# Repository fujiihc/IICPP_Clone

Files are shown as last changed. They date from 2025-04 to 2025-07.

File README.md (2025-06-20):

# IICPP_Clone
Mark IIC+/++ Inspired Clone

## Overview
This goal of this project was to create a reasonably accurate "clone" of the Mesa Boogie Mark IIC+/++ Tube Amplifier. 
I was inspired by my love of Metallica and James Hetfield's rhythm playing, as well as my fascination with audio electronics.

These amplifiers can be considered legendary and are the subject of many discussions on what makes them so special and highly sought after.
Although a legitimate Mark IIC+ Reissue exists, as do many originals, these amps are often expensive, and vary in their component and feature choices.
I wouldn't consider this version to be a 100% perfect clone as there is not much accurate, detailed information on these amplifiers, and some of the schematics that are available have been noted to be incorrect. Certain components are also not readily available today, and so some design concessions have to be made. Modifications due to limited design information, component availability, limited budget, and design complexity were made. However, the core DNA and design choices of the original were followed as closely as possible and I  would consider this a reasonably faithful clone.
By having a more accessible, afforable, and reasonably accurate version, hopefully I can help contribute to others' tone chasing journeys, or help demystify (in some capacity) what makes these amps so special.

I currently do not own any Mesa Boogie amplifiers to base these designs off of. Instead, I have researched this amp in depth, scouring the internet for schematics, gut shots, and getting advice from others who have successfully built their own clones or similar amplifiers. 

A major goal of this project is to stay under a budget of $1800 (Half the price of a Reissue).

An important note, this project is for educational purposes and personal use only, and this repository is for documenting my learning progress and findings. I have no affiliation with Mesa Boogie or any sort of company or anything like that. I just like making stuff and playing guitar. Please don't sue me :)

## Table of Contents 
  **PROJECTS WERE CREATED IN KICAD 9.0**
  - [Custom Libraries](/Custom%20Libraries): Contains Custom Footprints for Parts Not Available from KICAD Default Libraries.
  - [Experiments](/Experiments): Contains Experimental Layouts and Ideas That Haven't Been Confirmed/Finalized.
  - [Graphic EQ](/Graphic%20EQ): Contains KICAD Projects with Schematics, PCB Designs, and Gerber Files for 5-Band EQ Driver and Slider Boards.
  - [Images](/Images): Contains Images for Various README's.
  - [Power Amp](/Power%20Amp): Contains KICAD Projects with Schematics, PCB Designs, and Gerber Files for Power Amp Boards.
  - [Power Supply](/Power%20Supply): Contains KICAD Projects with Schematics, PCB Designs, and Gerber Files for Power Supply Boards.
  - [Preamp](/Preamp): Contains KICAD Projects with Schematics, PCB Designs, and Gerber Files for Preamp Boards.

## Organizational/Research Spreadsheet
Contains Research Links, Bill of Materials, Instructions, Personal Findings, Notes, etc.
 - [Link to Google Sheet](https://docs.google.com/spreadsheets/d/1ZE0vuGfygjLFiTaHai0WybOM6v7LY0qXNIPXHzz1JHo/edit?usp=sharing)

## Google Drive
Contains Pictures, Schematics, Datasheets, Manuals, Etc. Just useful information I found along the way.
 - [Link to Google Drive](https://drive.google.com/drive/folders/1geqLoLI9ncoWVvD1H8Yl4hjtfwfBTIB6?usp=drive_link)

## Thank You's
The following people have been invaluable in the progress of this project, both directly and indirectly. Whether they posted schematics that they traced, or in-depth gut shots or photos of their own builds, or even answered my questions when I ran into roadblocks, I would like to thank them. I wouldn't have made this much progress without them:

  - [JAY OMEGA](https://boogieforum.com/members/jay-omega.83481/)

  - [JRB32](https://boogieforum.com/members/jrb32.41252/)

  - [DANO](https://boogieforum.com/members/dan__o.6723/)

  - [DANN VALENTINO](https://www.facebook.com/dann.valentino/)

  - [MATADOR](https://boogieforum.com/members/matador.84058/)

## To-Do/Future Plans

  - Create Modified C++ Compatible Preamp Board With Reverb
  - Create Modified C++ Compatible Preamp Board Without Reverb
  - Create Power Amp Board
  - Create Public Google Drive with Helpful Files (Pictures, Schematics, Datasheets, Manuals, Etc).

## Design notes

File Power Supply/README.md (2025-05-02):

# Power Supply

## Overview
The Power Supply for the IICPP contains the Main HT/B+ Taps as well as the Bias and Graphic EQ Power Supplies.

The board supports x2 (for 60W) and x4 (for 100W and Simul-Class) 300V 220uF Reservoir Caps.

## Status
  - Schematic, PCB Design, and Gerber for V1.0 of the Power Supply Board are Complete.
  - Gerbers generated for JLCPCB Manufacturing.

## Bill Of Materials
  - [Link to Google Sheet](https://docs.google.com/spreadsheets/d/1ZE0vuGfygjLFiTaHai0WybOM6v7LY0qXNIPXHzz1JHo/edit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)

## Notes
  - Bias Supply for SLOCLONE/DANO, Mesa Boogie, and JRB32 Schematics are incorrect. The correct Bias Supply Schematic is used in this V1.0, which was traced from original IIB and IIC+ Power Supply Boards.
  - Validated/Correct and Incorrect Bias Supply Versions and Validation Sources can be found in [Experiments](../Experiments)
    
## To-Do/Future Plans
  - Add/Remove Taps based on Power Transformer. Currently looking at Hammond 291ZZ.

## Images
Power Supply V1.0:
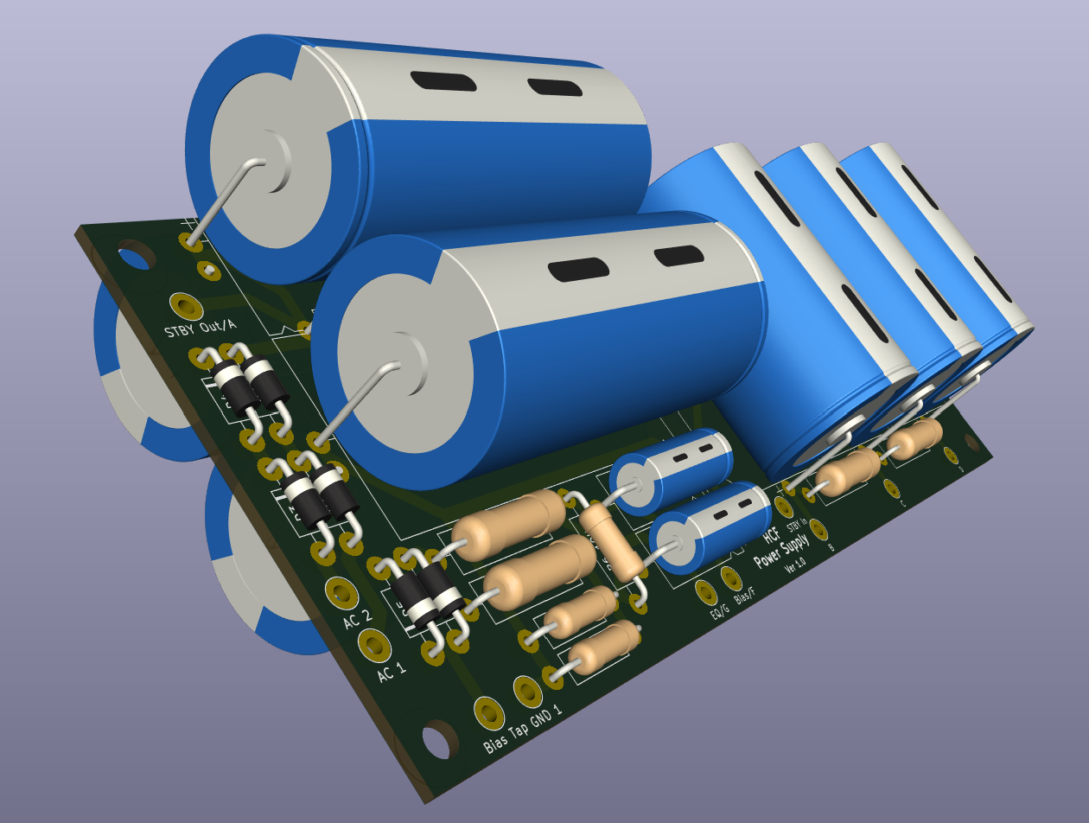
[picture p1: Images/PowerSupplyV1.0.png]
PowerSupplyV.10


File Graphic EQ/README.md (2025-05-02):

# Graphic EQ

## Overview
The 5-Band Graphic Equalizer for the IICPP consists of two parts, the EQ Driver and the EQ Slider Board. 

In conjunction, they can boost or cut frequencies at 80Hz, 240Hz, 750Hz, 2200Hz and 6600Hz.

The GEQ can be engaged in EQ Out, EQ In, and EQ Auto Modes, and can be footswitched.

EQ Out has the GEQ Off, EQ In has the GEQ In for Lead and Clean Modes, and EQ Auto engages the EQ when Lead is engaged.

## Status
  - Schematics, PCB Designs, and Gerbers for V1.0 of both the Driver and Slider Boards are Complete.
  - Gerbers generated for JLCPCB Manufacturing.

## Bill Of Materials
  - [Link to Google Sheet](https://docs.google.com/spreadsheets/d/1ZE0vuGfygjLFiTaHai0WybOM6v7LY0qXNIPXHzz1JHo/edit?gid=0#gid=0)

## Notes
  - MPSA70 is discontinued.
    - Options are NOS, finding drop-in replacement, or finding suitable alternatives for ALL transistors.
  - T322/T110 Tantalum Caps are expensive.
    - T322/T110 were used in some originals, but Cheaper Tant Caps (T356), Film Caps, or Orange Drop Caps also apparently work.
    
## To-Do/Future Plans
  - Order V1.0 Boards
  - Find Suitable Transistor Replacements

## Images
Slider V1.0:
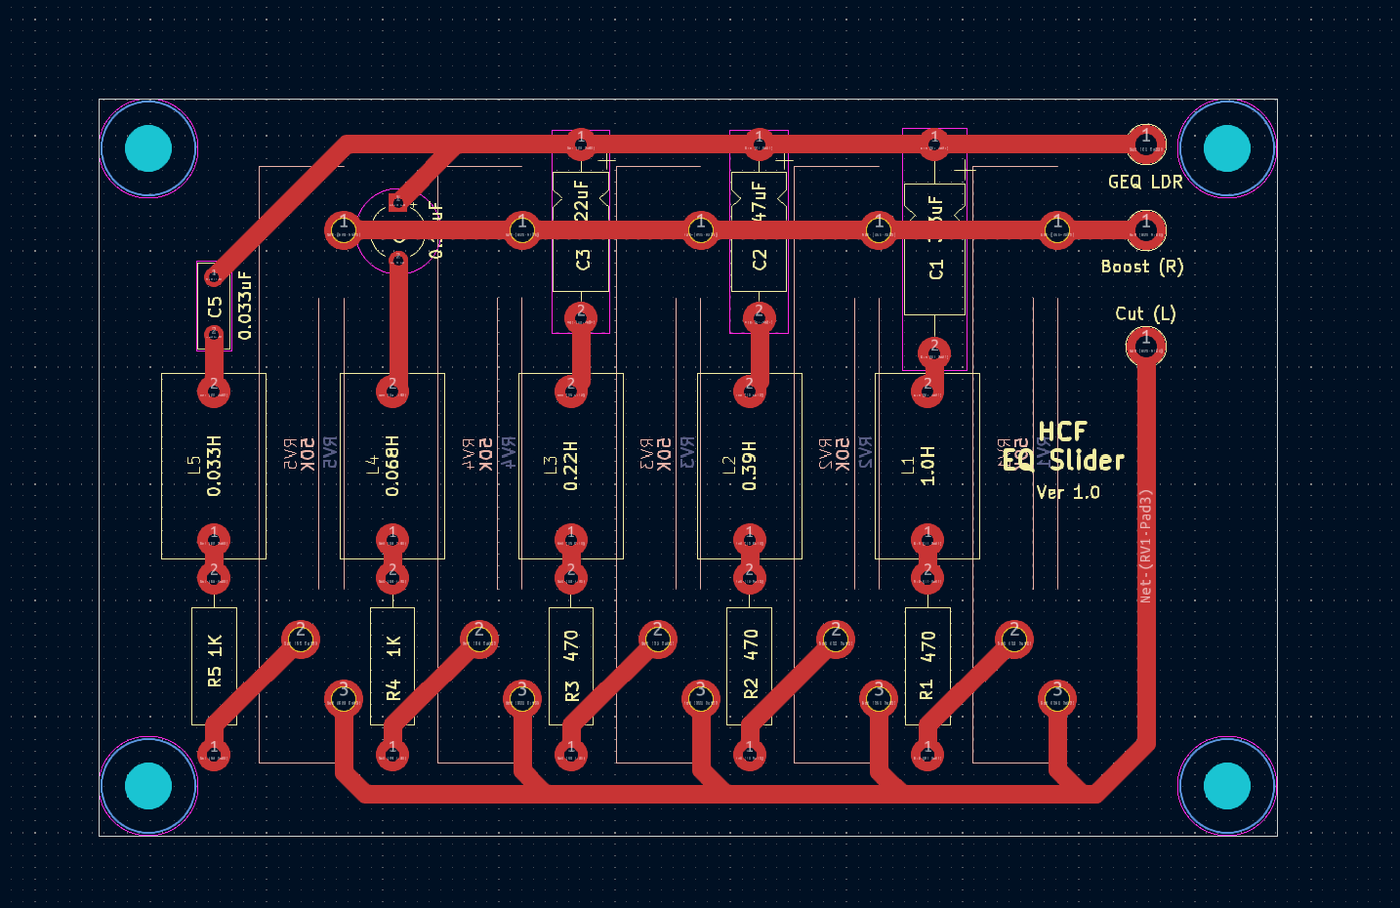
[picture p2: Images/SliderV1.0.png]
SliderV1.0


Driver V1.0:
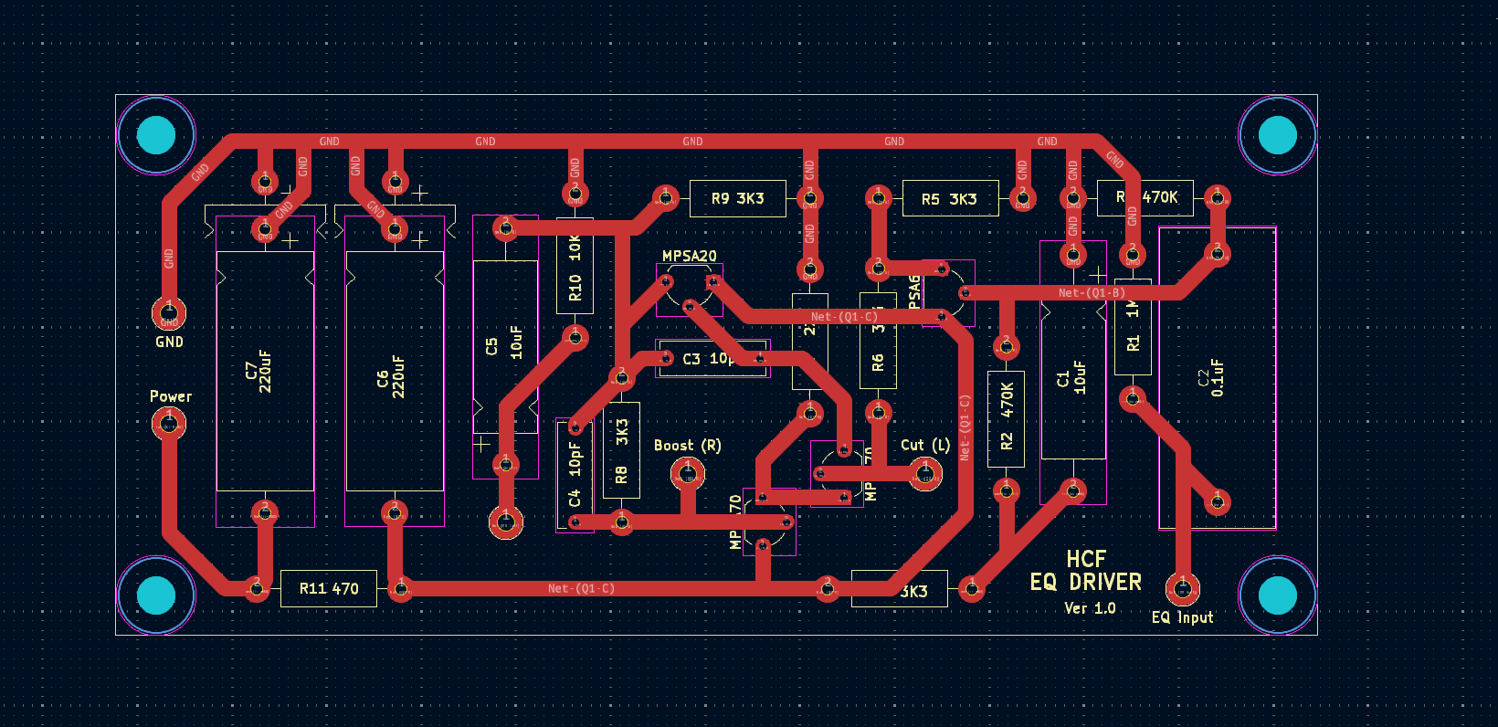
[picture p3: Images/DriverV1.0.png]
DriverV1.0


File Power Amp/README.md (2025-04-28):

# Power Amp

## Overview

## Status
  - 

## Bill Of Materials
  - [Link to Google Sheet](https://docs.google.com/spreadsheets/d/1ZE0vuGfygjLFiTaHai0WybOM6v7LY0qXNIPXHzz1JHo/edit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)

## Notes
  - 
## To-Do/Future Plans
  - 
## Images

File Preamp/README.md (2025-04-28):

# Preamp

## Overview
The Preamp for the IICPP has two switchable modes, Clean and Lead. There are also various Pull-Potentiometer/Switch Activated modes for tone shaping. 

It's important to note that the Tone Stack for the IICPP comes after the First Gain Stage, and before all the Following Gain Stages.
An optional mod for the IICPP is the "C++" Mod, which adds a little bit more gain on tap. This is an optional mod, but also switchable when implemented.

There are two versions of the Preamp here, one which has Reverb (R) and one with No Reverb (NR). the Reverb, when implemented, is footswitchable. The No Reverb version uses one less 12AX7 Preamp Tube, and uses fewer components as well.
The rest of the components and the schematic are the same.

## Status
  - 

## Bill Of Materials
  - [Link to Google Sheet](https://docs.google.com/spreadsheets/d/1ZE0vuGfygjLFiTaHai0WybOM6v7LY0qXNIPXHzz1JHo/edit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)

## Notes
  - 
## To-Do/Future Plans
  - 
## Images

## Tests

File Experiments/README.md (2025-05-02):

# Experiments

## Overview
Sometimes, schematics found online are different from what was actually implemented on the original IIC+'s.
The experiments folder is to mock up schematic and layout variations, for later validation. 

## Status
  - Correct Bias Supply Validated

## Sources
  - Bias Supply
    - Source 1: Original IIB Underside
    - Source 2: Original IIC+ Underside
    
## To-Do/Future Plans
  -

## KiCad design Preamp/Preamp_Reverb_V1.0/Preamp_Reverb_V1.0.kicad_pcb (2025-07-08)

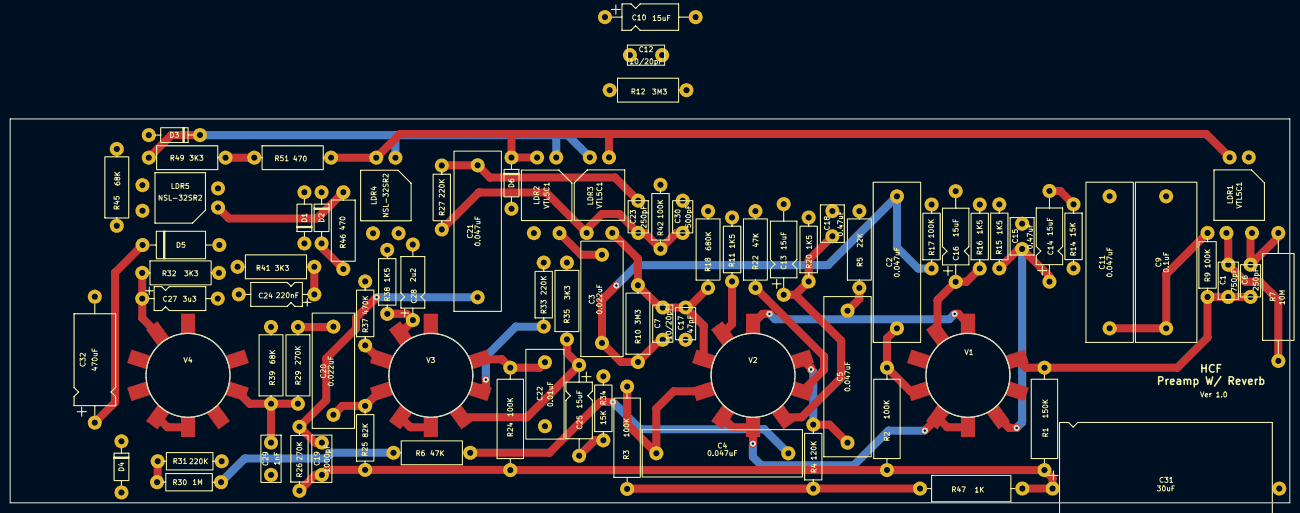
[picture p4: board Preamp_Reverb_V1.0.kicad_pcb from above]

Board: 2 copper layers, 254.0 x 76.2 mm, 84 parts (0 on the bottom side), 47 nets.

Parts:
C1: 750pF; 20_750pF_1KV_Cer_7.4_4.0_.6.4
C2, C4, C5, C11, C21: 0.047uF; 715P47354LAD3
C3, C20: 0.022uF; 715P22354KAD3
C6, C23: 250pF; 10_47_120_180_250_500pF_1KV_Cer_6.4_4.0_6.4
C7, C12: 10/20pF; 20_750pF_1KV_Cer_7.4_4.0_.6.4
C9: 0.1uF; 715P10454LAD3
C10, C13, C14, C16, C25: 15uF; CP_Axial_L11.0mm_D5.0mm_P18.00mm_Horizontal
C15, C18: 0.47uF; C_Rect_L7.2mm_W4.5mm_P5.00mm_FKS2_FKP2_MKS2_MKP2
C17: 47pF; 10_47_120_180_250_500pF_1KV_Cer_6.4_4.0_6.4
C19: 1000pF; 1000pF_1KV_Cer_9.4_4.0_6.4
C22: 0.01uF; 715P10354JAD3
C24: 220nF; CP_Axial_L10.0mm_D4.5mm_P15.00mm_Horizontal
C27: 3u3; CP_Axial_L10.0mm_D4.5mm_P15.00mm_Horizontal
C28: 2u2; CP_Axial_L10.0mm_D4.5mm_P15.00mm_Horizontal
C29: 1nF; 1000pF_1KV_Cer_9.4_4.0_6.4
C30: 500pF; 10_47_120_180_250_500pF_1KV_Cer_6.4_4.0_6.4
C31: 30uF; CP_Axial_L42.0mm_D26.0mm_P45.00mm_Horizontal
C32: 470uF; CP_Axial_L18.0mm_D8.0mm_P25.00mm_Horizontal
D1, D6: 6V 1W; D_DO-41_SOD81_P10.16mm_Horizontal
D2, D3, D4: 1N4006; D_DO-41_SOD81_P10.16mm_Horizontal
D5: 1N5352BRL; D_DO-201_P15.24mm_Horizontal
LDR1, LDR2, LDR3: VTL5C1; PerkinElmer_VTL5C
LDR4, LDR5: NSL-32SR2; PerkinElmer_VTL5C
R1: 150K; R_Axial_DIN0516_L15.5mm_D5.0mm_P20.32mm_Horizontal
R2, R3, R24: 100K; R_Axial_DIN0516_L15.5mm_D5.0mm_P20.32mm_Horizontal
R4: 120K; R_Axial_DIN0309_L9.0mm_D3.2mm_P12.70mm_Horizontal
R5: 22K; R_Axial_DIN0414_L11.9mm_D4.5mm_P15.24mm_Horizontal
R6, R22: 47K; R_Axial_DIN0414_L11.9mm_D4.5mm_P15.24mm_Horizontal
R7: 10M; R_Axial_DIN0617_L17.0mm_D6.0mm_P25.40mm_Horizontal
R9, R17, R42: 100K; R_Axial_DIN0309_L9.0mm_D3.2mm_P12.70mm_Horizontal
R10, R12: 3M3; R_Axial_DIN0414_L11.9mm_D4.5mm_P15.24mm_Horizontal
R11, R15, R16, R20, R38: 1K5; R_Axial_DIN0309_L9.0mm_D3.2mm_P12.70mm_Horizontal
R14, R34: 15K; R_Axial_DIN0309_L9.0mm_D3.2mm_P12.70mm_Horizontal
R18: 680K; R_Axial_DIN0414_L11.9mm_D4.5mm_P15.24mm_Horizontal
R25: 82K; R_Axial_DIN0309_L9.0mm_D3.2mm_P12.70mm_Horizontal
R26: 270K; R_Axial_DIN0309_L9.0mm_D3.2mm_P12.70mm_Horizontal
R27, R31, R33: 220K; R_Axial_DIN0309_L9.0mm_D3.2mm_P12.70mm_Horizontal
R29: 270K; R_Axial_DIN0414_L11.9mm_D4.5mm_P15.24mm_Horizontal
R30: 1M; R_Axial_DIN0309_L9.0mm_D3.2mm_P12.70mm_Horizontal
R32, R35, R41, R49: 3K3; R_Axial_DIN0414_L11.9mm_D4.5mm_P15.24mm_Horizontal
R37: 470K; R_Axial_DIN0309_L9.0mm_D3.2mm_P12.70mm_Horizontal
R39, R45: 68K; R_Axial_DIN0414_L11.9mm_D4.5mm_P15.24mm_Horizontal
R46, R51: 470; R_Axial_DIN0414_L11.9mm_D4.5mm_P15.24mm_Horizontal
R47: 1K; R_Axial_DIN0516_L15.5mm_D5.0mm_P20.32mm_Horizontal
V1, V2, V3, V4: 12AX7; VT9-ST-C

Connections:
D: R3.1, R4.1, R47.1
E: C19.1, C31.1, R1.1, R2.1, R24.1, R25.1, R26.1, R47.2
GEQ: LDR5.3, R45.1
GND: C15.2, C16.2, C17.2, C18.2, C27.2, C28.2, C29.2, C30.2, C31.2, C32.2, D1.2 (A), D5.2 (A), D6.2 (A), LDR4.3, LDR5.4, R11.2, R14.2, R15.2, R16.2, R17.2, R18.2, R20.2, R22.2, R31.2, R32.2, R33.2, R34.2, R35.2, R37.2, R38.2, R39.2, R41.2, R42.2, R45.2
LDR1+: D6.1 (K), LDR1.2 (+), LDR2.2 (+), LDR3.2 (+), LDR4.2 (+), R51.2
LDR2-: D3.1 (K), LDR2.1 (-), LDR3.1 (-), LDR4.1 (-), R49.2
Lead In: C3.2, LDR2.3
Lead Out: C7.2, C17.1, LDR3.4, R10.2, R18.1, V2.7 (G)
unnamed: C1.2, LDR1.4, R7.1
unnamed: C2.2, C3.1, C7.1, R10.1, R12.1, R17.1
unnamed: C4.2, R6.1
unnamed: C5.2, R5.1
unnamed: C6.2, LDR1.3, R7.2
unnamed: C9.1, C11.1, R9.2
unnamed: C12.1, R12.2
unnamed: C20.2, R29.1
unnamed: C21.2, C23.1, R27.1
unnamed: C23.2, C30.1, LDR3.3, R27.2, R42.1
unnamed: C25.2, R34.1
unnamed: D1.1 (K), LDR5.2 (+)
unnamed: D2.2 (A), R46.2
unnamed: C32.1, D5.1 (K), R49.1, R51.1
unnamed: LDR5.1 (-), R46.1
unnamed: C14.2, R14.1
unnamed: C2.1, R2.2, V1.6 (A)
unnamed: C16.1, R16.1, V1.8 (K)
unnamed: C1.1, C6.1, R1.2, R9.1, V1.1 (A)
unnamed: C14.1, C15.1, R15.1, V1.3 (K)
unnamed: V1.4 (F1), V1.5 (F1), V2.4 (F1), V2.5 (F1), V3.4 (F1), V3.5 (F1), V4.4 (F1), V4.5 (F1)
unnamed: V1.9 (F2), V2.9 (F2), V3.9 (F2), V4.9 (F2)
unnamed: C4.1, R3.2, V2.6 (A)
unnamed: C10.1, R11.1, V2.8 (K)
unnamed: C5.1, R4.2, V2.1 (A)
unnamed: R22.1, V2.2 (G)
unnamed: C13.1, C18.1, R20.1, V2.3 (K)
unnamed: C20.1, R25.2, V3.6 (A)
unnamed: R37.1, V3.7 (G)
unnamed: C28.1, R38.1, V3.8 (K)
unnamed: C22.1, R24.2, V3.1 (A)
unnamed: C25.1, R35.1, V3.3 (K)
unnamed: R30.2, R31.1, V4.7 (G)
unnamed: C27.1, R32.1, V4.8 (K)
unnamed: C19.2, C21.1, R26.2, V4.1 (A)
unnamed: C29.1, R29.2, R39.1, V4.2 (G)
unnamed: C24.1, R41.1, V4.3 (K)
Reverb In: R6.2, R30.1
Tank Out: R33.1, V3.2 (G)

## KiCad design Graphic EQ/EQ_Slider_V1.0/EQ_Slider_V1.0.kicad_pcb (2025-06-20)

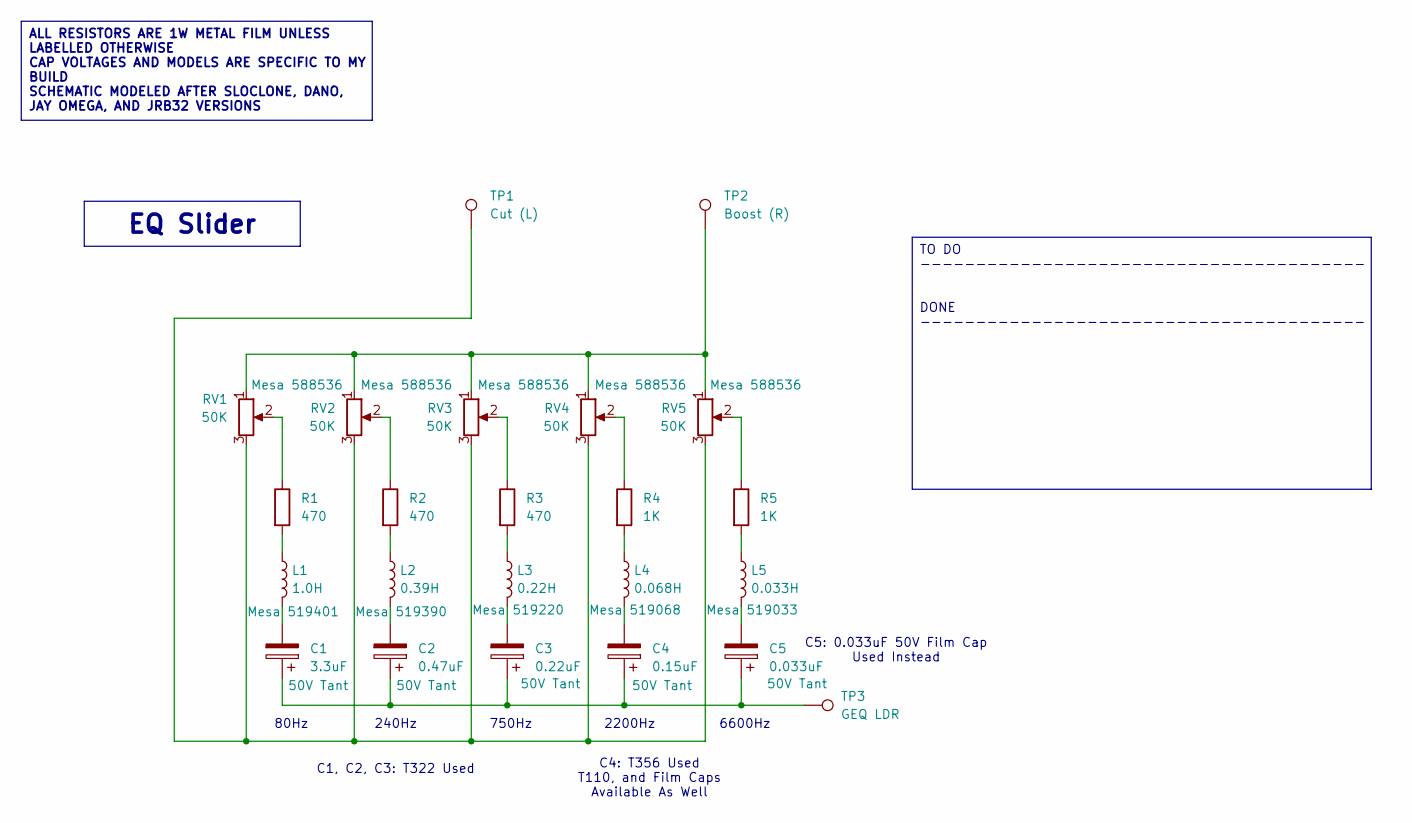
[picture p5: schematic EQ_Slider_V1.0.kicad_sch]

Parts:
C1: 3.3uF; CP_Axial_L11.0mm_D5.0mm_P18.00mm_Horizontal
C2: 0.47uF; CP_Axial_L10.0mm_D4.5mm_P15.00mm_Horizontal
C3: 0.22uF; CP_Axial_L10.0mm_D4.5mm_P15.00mm_Horizontal
C4: 0.15uF; CP_Radial_Tantal_D4.5mm_P5.00mm
C5: 0.033uF; C_Rect_L7.2mm_W2.5mm_P5.00mm_FKS2_FKP2_MKS2_MKP2
L1: 1.0H; MB Inductor
L2: 0.39H; MB Inductor
L3: 0.22H; MB Inductor
L4: 0.068H; MB Inductor
L5: 0.033H; MB Inductor
R1, R2, R3: 470; R_Axial_DIN0414_L11.9mm_D4.5mm_P15.24mm_Horizontal
R4, R5: 1K; R_Axial_DIN0414_L11.9mm_D4.5mm_P15.24mm_Horizontal
RV1, RV2, RV3, RV4, RV5: 50K; Mesa 588536
TP1: Cut (L); Out_Hole_3.4_1.8
TP2: Boost (R); Out_Hole_3.4_1.8
TP3: GEQ LDR; Out_Hole_3.4_1.8

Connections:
unnamed: C1.1, C2.1, C3.1, C4.1, C5.1, TP3.1
unnamed: C1.2, L1.2
unnamed: C2.2, L2.2
unnamed: C3.2, L3.2
unnamed: C4.2, L4.2
unnamed: C5.2, L5.2
unnamed: L1.1, R1.2
unnamed: L2.1, R2.2
unnamed: L3.1, R3.2
unnamed: L4.1, R4.2
unnamed: L5.1, R5.2
unnamed: R1.1, RV1.2
unnamed: R2.1, RV2.2
unnamed: R3.1, RV3.2
unnamed: R4.1, RV4.2
unnamed: R5.1, RV5.2
unnamed: RV1.1, RV2.1, RV3.1, RV4.1, RV5.1, TP2.1
unnamed: RV1.3, RV2.3, RV3.3, RV4.3, RV5.3, TP1.1

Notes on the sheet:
C5: 0.033uF 50V Film Cap Used Instead
750Hz
80Hz
240Hz
6600Hz
C4: T356 Used T110, and Film Caps Available As Well
2200Hz
C1, C2, C3: T322 Used
ALL RESISTORS ARE 1W METAL FILM UNLESS LABELLED OTHERWISE CAP VOLTAGES AND MODELS ARE SPECIFIC TO MY BUILD SCHEMATIC MODELED AFTER SLOCLONE, DANO, JAY OMEGA, AND JRB32 VERSIONS
TO DO ---------------------------------------- DONE ----------------------------------------
EQ Slider

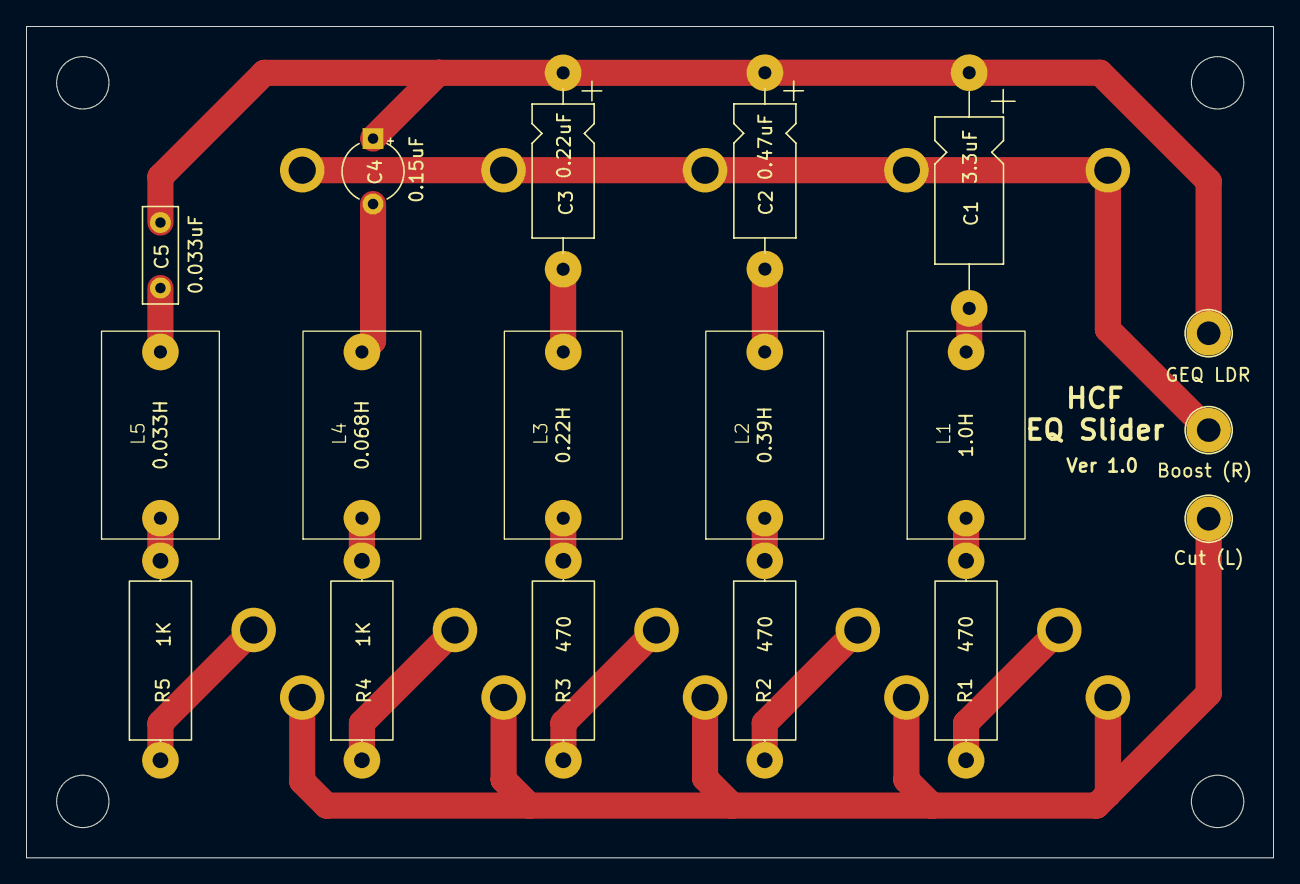
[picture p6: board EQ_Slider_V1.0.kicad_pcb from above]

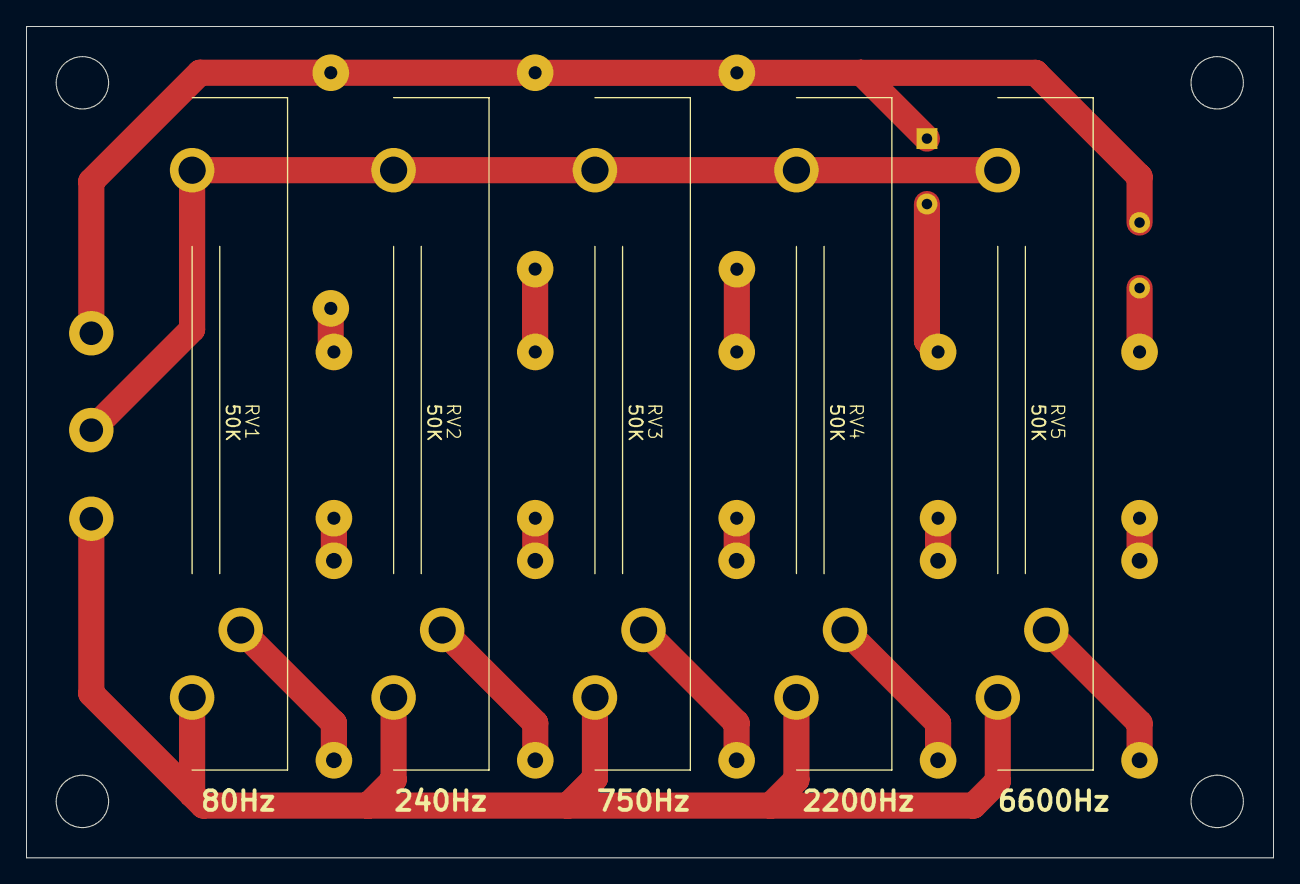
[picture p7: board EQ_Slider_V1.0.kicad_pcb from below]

Board: 2 copper layers, 95.3 x 63.5 mm, 23 parts (5 on the bottom side), 18 nets.

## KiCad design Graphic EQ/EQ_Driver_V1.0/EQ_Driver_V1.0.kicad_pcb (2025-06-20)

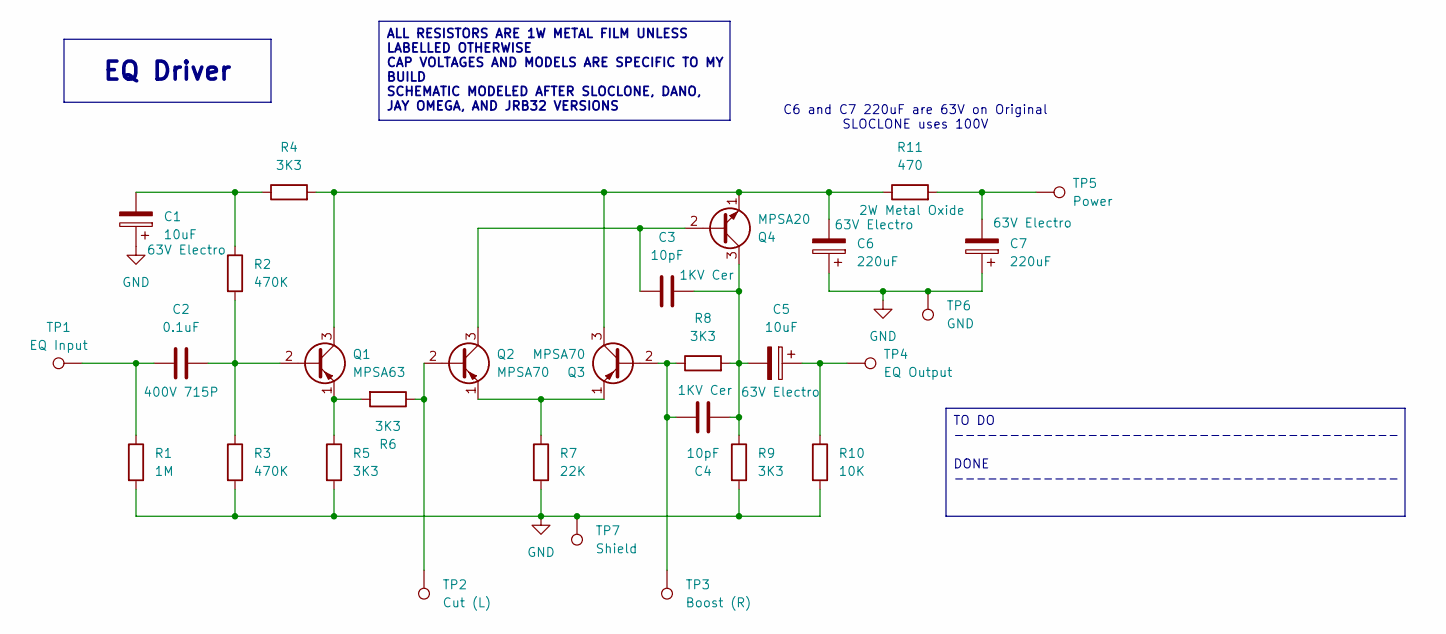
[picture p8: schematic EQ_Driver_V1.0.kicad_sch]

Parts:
C1, C5: 10uF; CP_Axial_L18.0mm_D6.5mm_P25.00mm_Horizontal
C2: 0.1uF; 715P10454LAD3
C3, C4: 10pF; 10_47_120_180_250_500pF_1KV_Cer_6.4_4.0_6.4
C6, C7: 220uF; CP_Axial_L25.0mm_D10.0mm_P30.00mm_Horizontal
Q1: MPSA63; TO-92_Wide
Q2, Q3: MPSA70; TO-92_Wide
Q4: MPSA20; TO-92_Wide
R1: 1M; R_Axial_DIN0309_L9.0mm_D3.2mm_P12.70mm_Horizontal
R2, R3: 470K; R_Axial_DIN0309_L9.0mm_D3.2mm_P12.70mm_Horizontal
R4, R5, R6, R8, R9: 3K3; R_Axial_DIN0414_L11.9mm_D4.5mm_P15.24mm_Horizontal
R7: 22K; R_Axial_DIN0414_L11.9mm_D4.5mm_P15.24mm_Horizontal
R10: 10K; R_Axial_DIN0309_L9.0mm_D3.2mm_P12.70mm_Horizontal
R11: 470; R_Axial_DIN0516_L15.5mm_D5.0mm_P20.32mm_Horizontal
TP1: EQ Input; WirePad
TP2: Cut (L); WirePad
TP3: Boost (R); WirePad
TP4: EQ Output; Out_Hole_3.4_1.8
TP5: Power; Out_Hole_3.4_1.8
TP6: GND; WirePad
TP7: Shield; WirePad

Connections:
GND: C1.1, C6.1, C7.1, R1.2, R3.2, R5.2, R7.2, R9.2, R10.2, TP6.1, TP7.1
unnamed: C1.2, R2.1, R4.1
unnamed: C2.1, R1.1, TP1.1
unnamed: C5.1, R10.1, TP4.1
unnamed: C7.2, R11.2, TP5.1
unnamed: C2.2, Q1.2 (B), R2.2, R3.1
unnamed: C6.2, Q1.3 (C), Q3.3 (C), Q4.1 (E), R4.2, R11.1
unnamed: Q1.1 (E), R5.1, R6.2
unnamed: Q2.2 (B), R6.1, TP2.1
unnamed: C3.1, Q2.3 (C), Q4.2 (B)
unnamed: Q2.1 (E), Q3.1 (E), R7.1
unnamed: C4.1, Q3.2 (B), R8.1, TP3.1
unnamed: C3.2, C4.2, C5.2, Q4.3 (C), R8.2, R9.1

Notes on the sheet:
C6 and C7 220uF are 63V on Original SLOCLONE uses 100V
EQ Driver
ALL RESISTORS ARE 1W METAL FILM UNLESS LABELLED OTHERWISE CAP VOLTAGES AND MODELS ARE SPECIFIC TO MY BUILD SCHEMATIC MODELED AFTER SLOCLONE, DANO, JAY OMEGA, AND JRB32 VERSIONS
TO DO ---------------------------------------- DONE ----------------------------------------

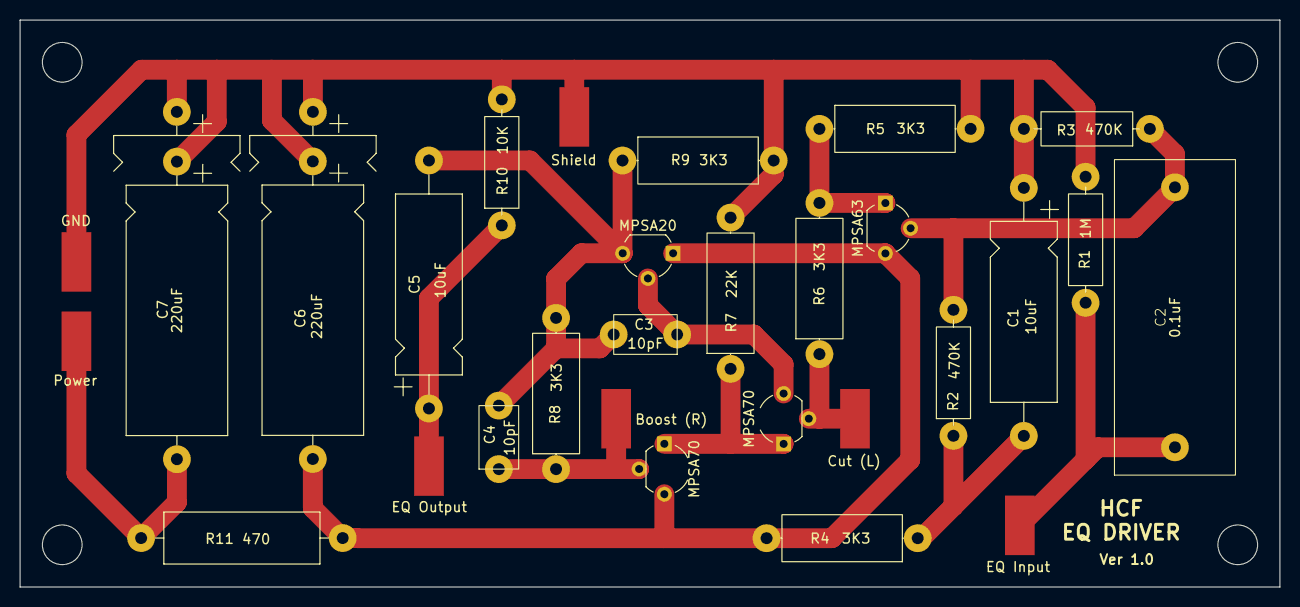
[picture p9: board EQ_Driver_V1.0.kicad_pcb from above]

Board: 2 copper layers, 127.0 x 57.2 mm, 29 parts (0 on the bottom side), 13 nets.

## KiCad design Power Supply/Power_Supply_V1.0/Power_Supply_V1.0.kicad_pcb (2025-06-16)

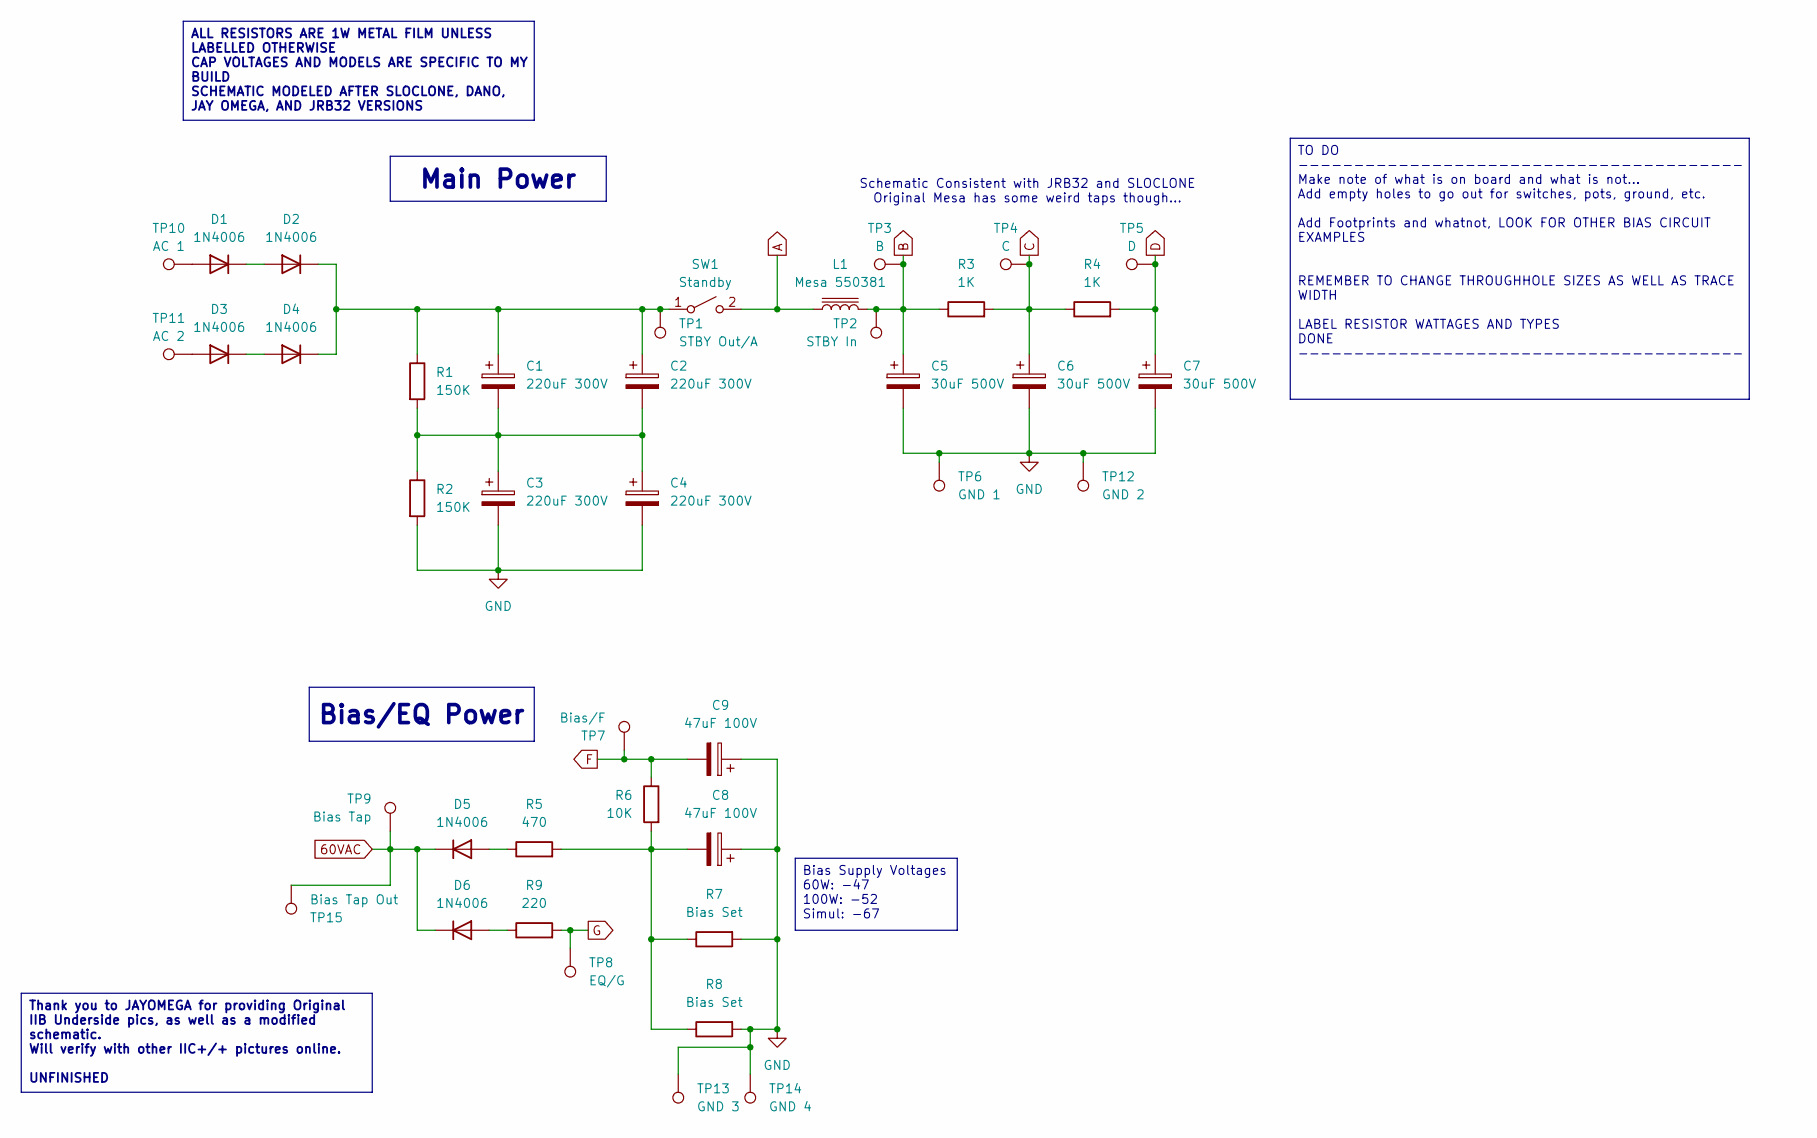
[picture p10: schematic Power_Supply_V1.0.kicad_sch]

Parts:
C1, C2, C3, C4: 220uF 300V; CP_Axial_L55.0mm_D26.0mm_P60.00mm_Horizontal
C5, C6, C7: 30uF 500V; CP_Axial_L42.0mm_D26.0mm_P45.00mm_Horizontal
C8, C9: 47uF 100V; CP_Axial_L18.0mm_D8.0mm_P25.00mm_Horizontal
D1, D2, D3, D4, D5, D6: 1N4006; D_DO-41_SOD81_P10.16mm_Horizontal
L1: Mesa 550381
R1, R2: 150K; R_Axial_DIN0516_L15.5mm_D5.0mm_P20.32mm_Horizontal
R3, R4: 1K; R_Axial_DIN0516_L15.5mm_D5.0mm_P20.32mm_Horizontal
R5: 470; R_Axial_DIN0516_L15.5mm_D5.0mm_P20.32mm_Horizontal
R6: 10K; R_Axial_DIN0309_L9.0mm_D3.2mm_P12.70mm_Horizontal
R7, R8: Bias Set; R_Axial_DIN0309_L9.0mm_D3.2mm_P12.70mm_Horizontal
R9: 220; R_Axial_DIN0516_L15.5mm_D5.0mm_P20.32mm_Horizontal
SW1: Standby
TP1: STBY Out/A; Out_Hole_3.4_1.8
TP2: STBY In; Out_Hole_3.4_1.8
TP3: B; WirePad
TP4: C; WirePad
TP5: D; WirePad
TP6: GND 1; WirePad
TP7: Bias/F; WirePad
TP8: EQ/G; WirePad
TP9: Bias Tap; Out_Hole_3.4_1.8
TP10: AC 1; Out_Hole_3.4_1.8
TP11: AC 2; Out_Hole_3.4_1.8
TP12: GND 2; WirePad
TP13: GND 3; WirePad
TP14: GND 4; WirePad
TP15: Bias Tap Out; WirePad

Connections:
60VAC: D5.1 (K), D6.1 (K), TP9.1, TP15.1
B: C5.1, L1.2, R3.1, TP2.1, TP3.1
C: C6.1, R3.2, R4.1, TP4.1
D: C7.1, R4.2, TP5.1
F: C9.2, R6.1, TP7.1
G: R9.2, TP8.1
GND: C3.2, C4.2, C5.2, C6.2, C7.2, C8.1, C9.1, R2.2, R7.2, R8.2, TP6.1, TP12.1, TP13.1, TP14.1
unnamed: C1.2, C2.2, C3.1, C4.1, R1.2, R2.1
unnamed: C8.2, R5.2, R6.2, R7.1, R8.1
unnamed: D1.2 (A), TP10.1
unnamed: D1.1 (K), D2.2 (A)
unnamed: C1.1, C2.1, D2.1 (K), D4.1 (K), R1.1, SW1.1 (A), TP1.1
unnamed: D3.2 (A), TP11.1
unnamed: D3.1 (K), D4.2 (A)
unnamed: D5.2 (A), R5.1
unnamed: D6.2 (A), R9.1
unnamed: L1.1, SW1.2 (B)

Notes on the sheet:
Schematic Consistent with JRB32 and SLOCLONE Original Mesa has some weird taps though...
Thank you to JAYOMEGA for providing Original IIB Underside pics, as well as a modified schematic. Will verify with other IIC+/+ pictures online. UNFINISHED
ALL RESISTORS ARE 1W METAL FILM UNLESS LABELLED OTHERWISE CAP VOLTAGES AND MODELS ARE SPECIFIC TO MY BUILD SCHEMATIC MODELED AFTER SLOCLONE, DANO, JAY OMEGA, AND JRB32 VERSIONS
Main Power
Bias/EQ Power
TO DO ---------------------------------------- Make note of what is on board and what is not... Add empty holes to go out for switches, pots, ground, etc. Add Footprints and whatnot, LOOK FOR OTHER BIAS CIRCUIT EXAMPLES REMEMBER TO CHANGE THROUGHHOLE SIZES AS WELL AS TRACE WIDTH LABEL RESISTOR WATT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
Bias Supply Voltages 60W: -47 100W: -52 Simul: -67

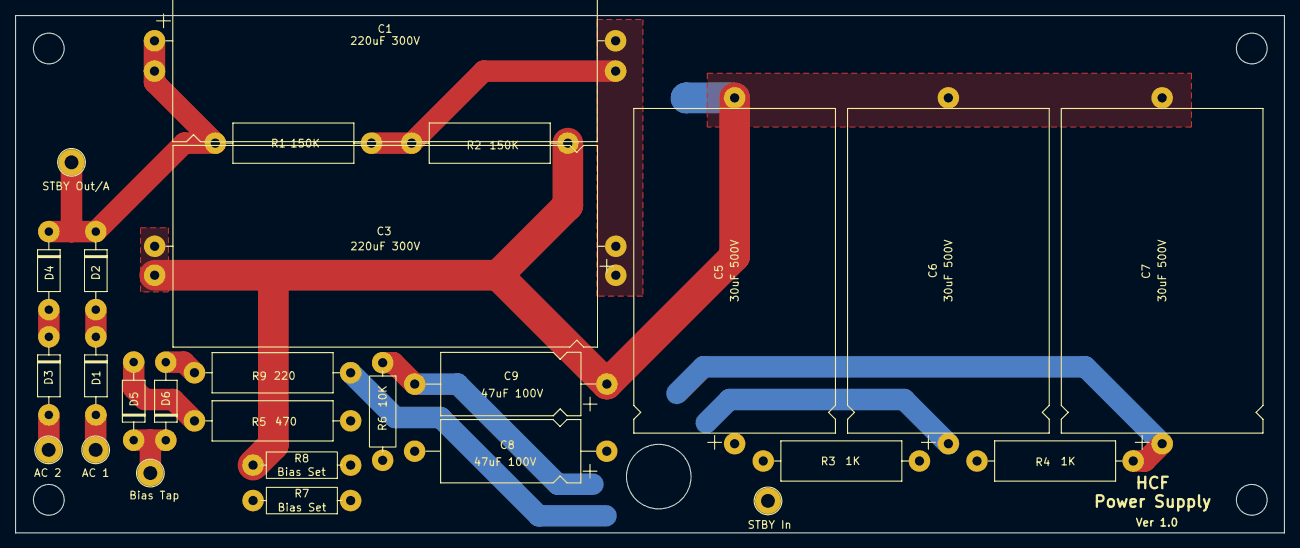
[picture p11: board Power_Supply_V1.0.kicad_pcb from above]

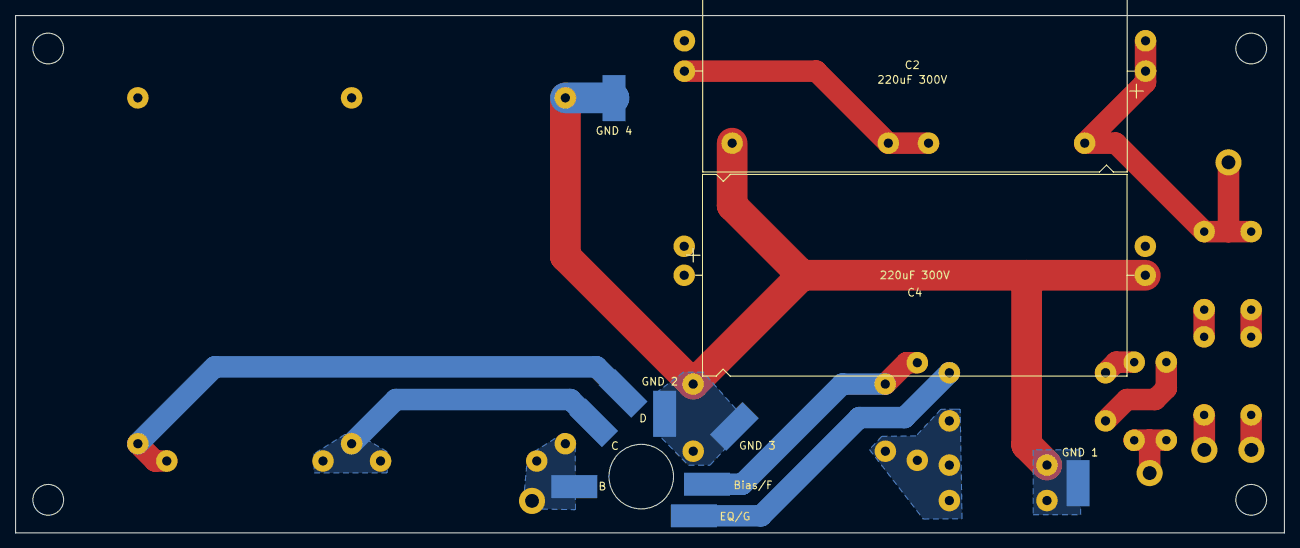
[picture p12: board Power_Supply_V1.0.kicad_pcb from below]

Board: 2 copper layers, 165.1 x 67.3 mm, 38 parts (11 on the bottom side), 16 nets.

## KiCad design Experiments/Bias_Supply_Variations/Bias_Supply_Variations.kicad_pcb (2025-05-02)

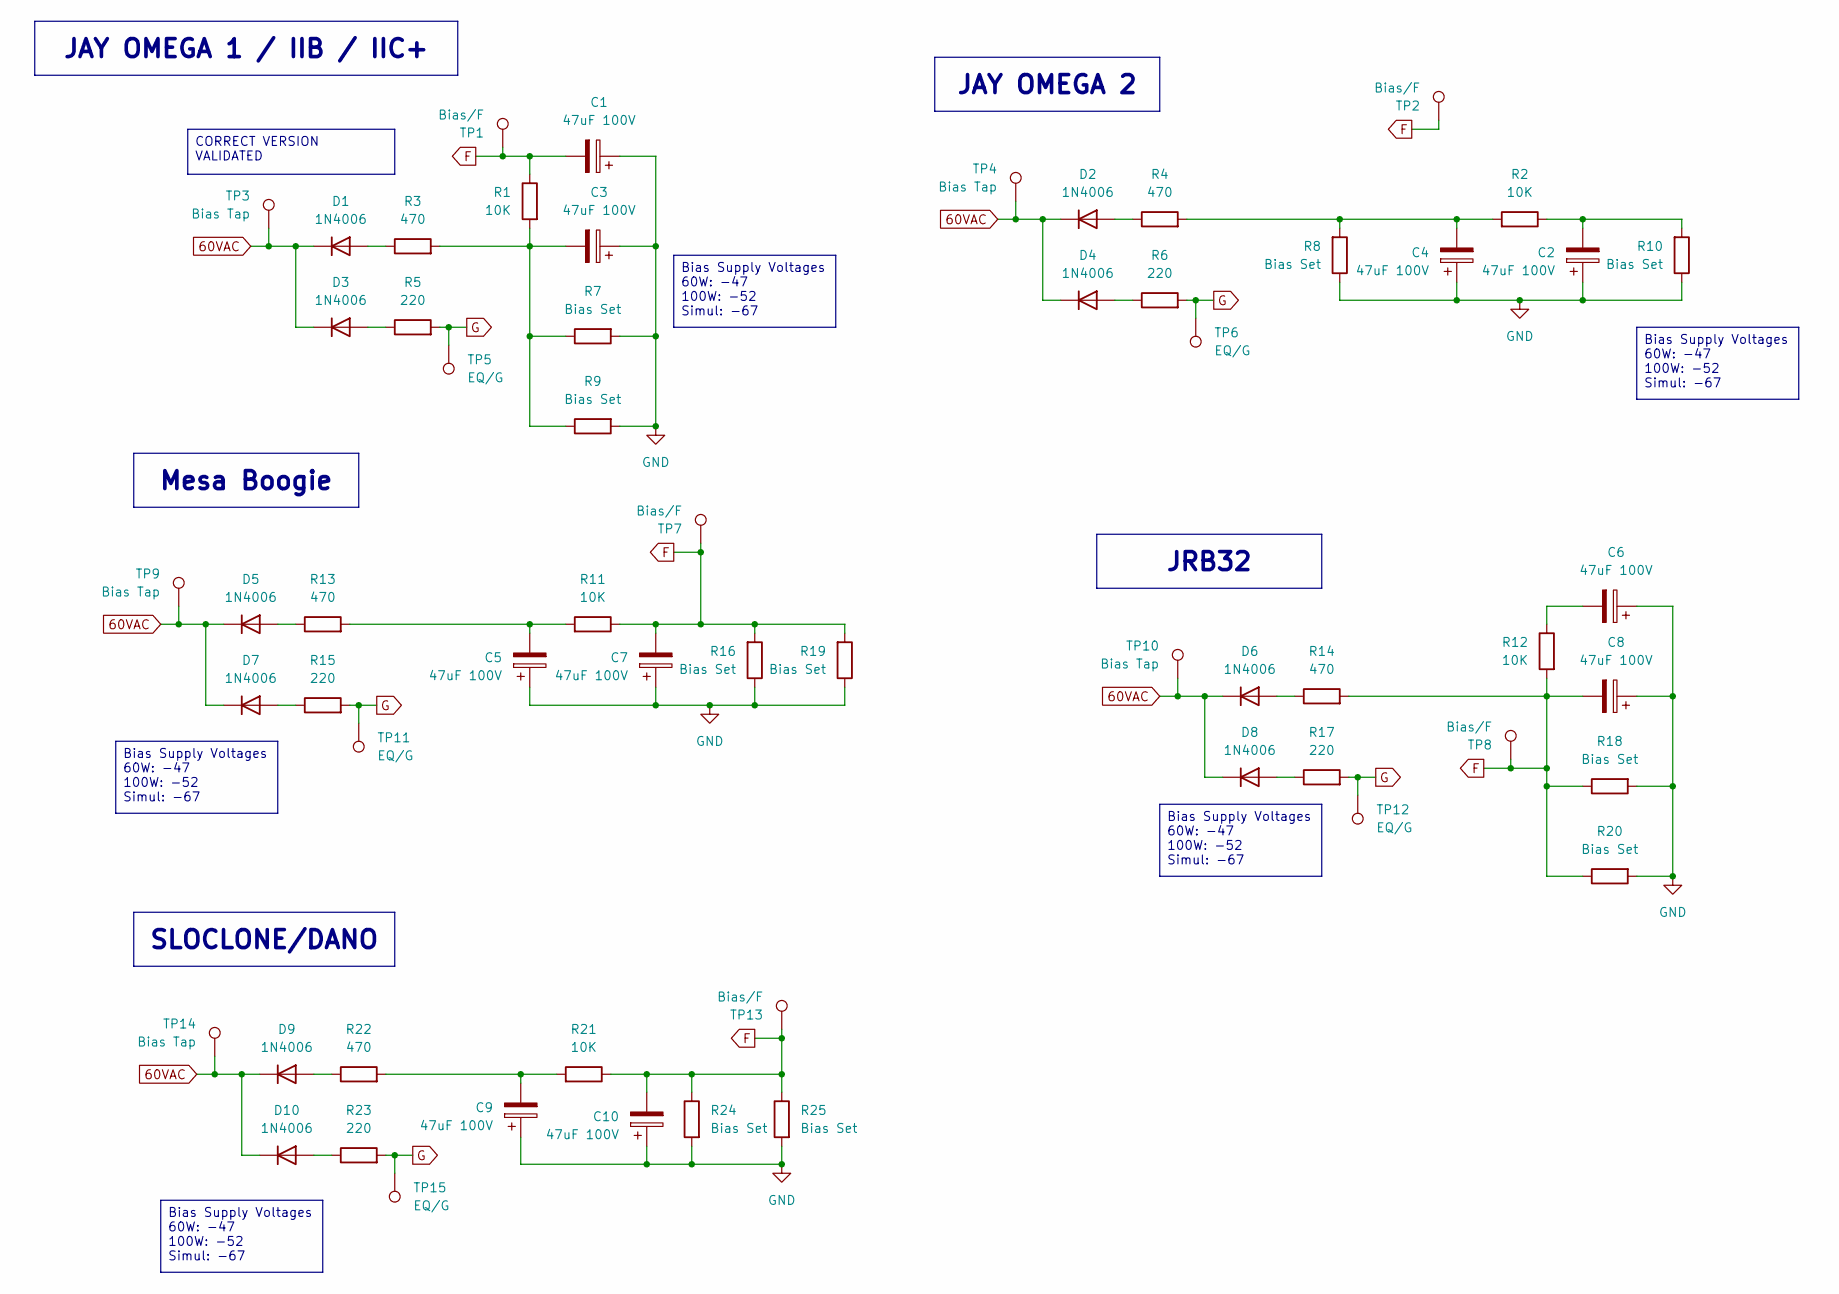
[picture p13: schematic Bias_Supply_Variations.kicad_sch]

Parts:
C1, C2, C3, C4, C5, C6, C7, C8, C9, C10: 47uF 100V; CP_Axial_L18.0mm_D8.0mm_P25.00mm_Horizontal
D1, D2, D3, D4, D5, D6, D7, D8, D9, D10: 1N4006; D_DO-41_SOD81_P10.16mm_Horizontal
R1, R2, R11, R12, R21: 10K; R_Axial_DIN0411_L9.9mm_D3.6mm_P15.24mm_Horizontal
R3, R4, R13, R14, R22: 470; R_Axial_DIN0516_L15.5mm_D5.0mm_P20.32mm_Horizontal
R5, R6, R15, R17, R23: 220; R_Axial_DIN0516_L15.5mm_D5.0mm_P20.32mm_Horizontal
R7, R8, R9, R10, R16, R18, R19, R20, R24, R25: Bias Set; R_Axial_DIN0411_L9.9mm_D3.6mm_P15.24mm_Horizontal
TP1, TP2, TP7, TP8, TP13: Bias/F; Out_Hole_3.4_1.8
TP3, TP4, TP9, TP10, TP14: Bias Tap; Out_Hole_3.4_1.8
TP5, TP6, TP11, TP12, TP15: EQ/G; Out_Hole_3.4_1.8

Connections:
60VAC: D1.1 (K), D2.1 (K), D3.1 (K), D4.1 (K), D5.1 (K), D6.1 (K), D7.1 (K), D8.1 (K), D9.1 (K), D10.1 (K), TP3.1, TP4.1, TP9.1, TP10.1, TP14.1
F: C1.2, C7.2, C8.2, C10.2, R1.1, R11.1, R12.2, R14.2, R16.2, R18.1, R19.2, R20.1, R21.1, R24.1, R25.1, TP1.1, TP2.1, TP7.1, TP8.1, TP13.1
G: R5.2, R6.2, R15.2, R17.2, R23.2, TP5.1, TP6.1, TP11.1, TP12.1, TP15.1
GND: C1.1, C2.1, C3.1, C4.1, C5.1, C6.1, C7.1, C8.1, C9.1, C10.1, R7.2, R8.1, R9.2, R10.1, R16.1, R18.2, R19.1, R20.2, R24.2, R25.2
unnamed: C2.2, R2.1, R10.2
unnamed: C3.2, R1.2, R3.2, R7.1, R9.1
unnamed: C4.2, R2.2, R4.2, R8.2
unnamed: C5.2, R11.2, R13.2
unnamed: C6.2, R12.1
unnamed: C9.2, R21.2, R22.2
unnamed: D1.2 (A), R3.1
unnamed: D2.2 (A), R4.1
unnamed: D3.2 (A), R5.1
unnamed: D4.2 (A), R6.1
unnamed: D5.2 (A), R13.1
unnamed: D6.2 (A), R14.1
unnamed: D7.2 (A), R15.1
unnamed: D8.2 (A), R17.1
unnamed: D9.2 (A), R22.1
unnamed: D10.2 (A), R23.1

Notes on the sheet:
Bias Supply Voltages 60W: -47 100W: -52 Simul: -67
Mesa Boogie
JAY OMEGA 1 / IIB / IIC+
SLOCLONE/DANO
JAY OMEGA 2
JRB32
CORRECT VERSION VALIDATED

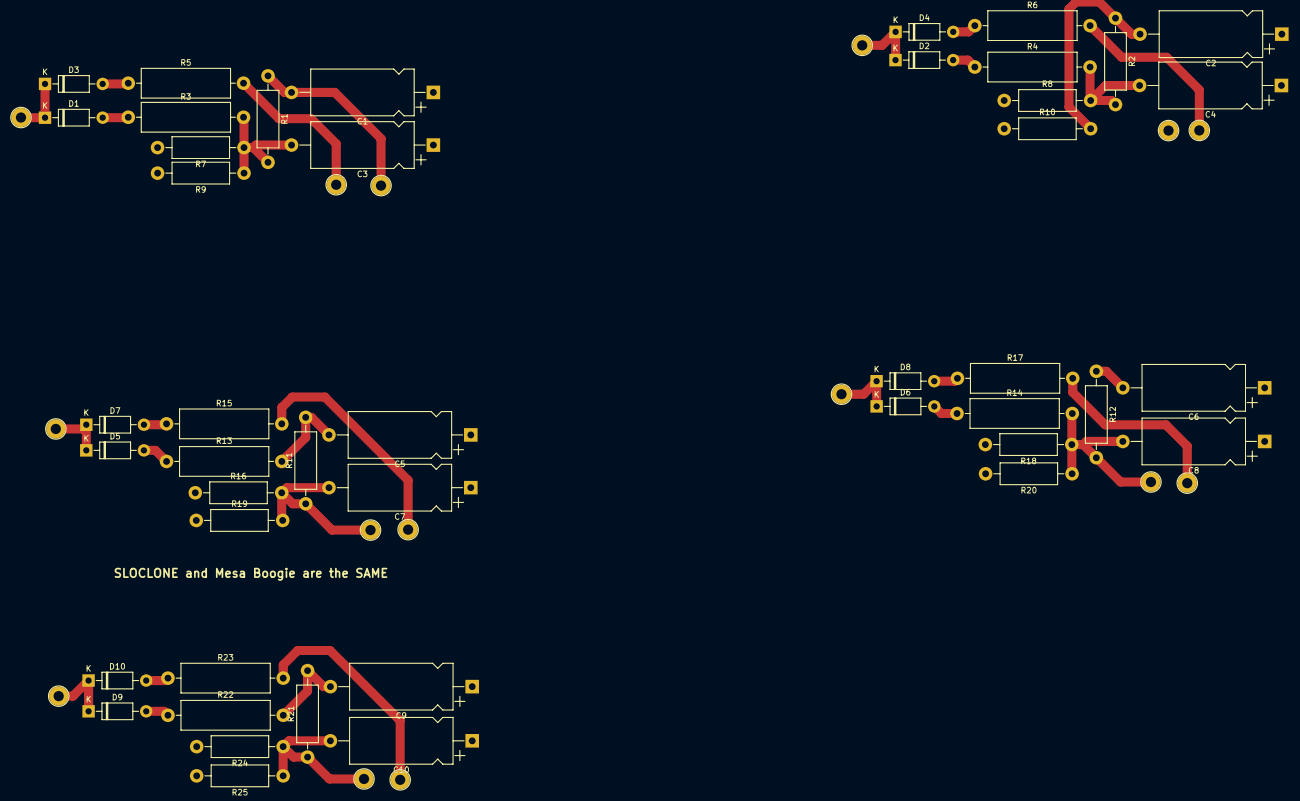
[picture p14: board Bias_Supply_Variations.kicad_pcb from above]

Board: 2 copper layers, 60 parts (0 on the bottom side), 20 nets.

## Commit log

2025-04-08 Added First Schems
    [EQ_Board.kicad_pcb, EQ_Board.kicad_sch, EQ_Driver_Board.kicad_pcb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]
2025-04-08 Reannotated Schems
    [EQ_Board.kicad_sch, EQ_Driver_Board.kicad_sch, Preamp_Board.kicad_sch]
2025-04-08 Added Annotations
    [EQ_Board.kicad_sch, EQ_Driver_Board.kicad_sch, Preamp_Board.kicad_sch]
2025-04-24 Updated Schematics and Organizational Structure
    [Classic_Preamp_Board_NR_EQ.kicad_pcb, Classic_Preamp_Board_NR_EQ.kicad_sch, Classic_Preamp_Board_R_EQ.kicad_pcb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]
2025-04-25 EQ Slider Board Progress
    [EQ_Driver_Board.kicad_pcb, EQ_Slider_Board.kicad_pcb, EQ_Slider_Board.kicad_sch]
2025-04-25 Finished EQ Slider V1 Board
    [EQ_Slider_Board.kicad_pcb, EQ_Slider_Board.kicad_sch]
2025-04-25 organizational changes
    [Classic_Preamp_Board_NR_EQ.kicad_pcb, Classic_Preamp_Board_NR_EQ.kicad_sch, Classic_Preamp_Board_R_EQ.kicad_pcb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]
2025-04-25 Added Comments to EQ Slider PCB
    [EQ_Slider_V1.0.kicad_pcb, EQ_Slider_V1.0.kicad_sch]
2025-04-27 Added EQ Driver/Slider V1.0 Gerbers
    [EQ_Driver_V1.0.kicad_pcb, EQ_Driver_V1.0.kicad_sch, EQ_Slider_V1.0.kicad_pcb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]
2025-04-28 Updated Driver V1.0 Gerber
    [EQ_Driver_V1.0.kicad_pcb, EQ_Driver_V1.0.kicad_sch]
2025-04-28 Updated V1.0 Driver Board
    [EQ_Driver_V1.0.kicad_pcb]
2025-04-29 Started Power Supply Board, Made EQ Driver Changes
    [EQ_Driver_V1.0.kicad_pcb, EQ_Driver_V1.0.kicad_sch, Power_Supply_Board.kicad_pcb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]
2025-04-29 Power Supply Board Progress
    [Power_Supply_Board.kicad_pcb, Power_Supply_Board.kicad_sch]
2025-04-30 Completed Initial Mockup of Power Supply Board PCB
    [Power_Supply_Board.kicad_pcb]
2025-04-30 Added Power Supply V1.0 Gerber
    [Power_Supply_V1.0.kicad_pcb, Power_Supply_V1.0.kicad_sch]
2025-04-30 organizational change
    [Power_Supply_Board.kicad_pcb, Power_Supply_Board.kicad_sch]
2025-05-01 Updated Gerber
    [Power_Supply_V1.0.kicad_pcb]
2025-05-01 Condensed Reservoir Caps
    [Power_Supply_V1.0.kicad_pcb]
2025-05-02 Added Bias Supply Experiments
    [Bias_Supply_Variations.kicad_pcb, Bias_Supply_Variations.kicad_sch]
2025-05-02 added Power Supply V1.0 Images
2025-05-02 Created Different Bias Schematics and Layout for Future Reference
    [Bias_Supply_Variations.kicad_pcb]
2025-05-02 Validated Correct Bias Supply Schematic/Layout
    [Bias_Supply_Variations.kicad_pcb, Bias_Supply_Variations.kicad_sch]
2025-05-02 increased ground trace in PSV1.0
    [Power_Supply_V1.0.kicad_pcb]
2025-05-04 Started Preamp Boards
    [Preamp_NoReverb_V1.0.kicad_pcb, Preamp_NoReverb_V1.0.kicad_sch, Preamp_Reverb_V1.0.kicad_pcb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]
2025-05-04 remove old versions of preamp layout
    [Classic_Preamp_Board_NR_EQ.kicad_pcb, Classic_Preamp_Board_NR_EQ.kicad_sch, Classic_Preamp_Board_R_EQ.kicad_pcb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]
2025-05-10 Added test points to preamp board for layout planning
    [Preamp_Reverb_V1.0.kicad_sch]
2025-05-11 Preamp Board Progress
    [Preamp_Reverb_V1.0.kicad_sch]
2025-05-27 small updates
    [EQ_Driver_V1.0.kicad_pcb, EQ_Slider_V1.0.kicad_pcb]
2025-05-27 Changed Driver Layout
    [EQ_Driver_V1.0.kicad_pcb]
2025-05-30 Added Solder Pads, Updated Power Supply Board
    [EQ_Driver_V1.0.kicad_pcb, EQ_Driver_V1.0.kicad_sch, Power_Supply_V1.0.kicad_pcb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]
2025-05-30 Power Supply progress
    [Power_Supply_V1.0.kicad_pcb]
2025-05-30 Made slider board more compact
    [EQ_Slider_V1.0.kicad_pcb]
2025-06-01 increased trace width
    [EQ_Driver_V1.0.kicad_pcb, EQ_Slider_V1.0.kicad_pcb, Power_Supply_V1.0.kicad_pcb]
2025-06-01 updated power supply board with more diode spacing
    [Power_Supply_V1.0.kicad_pcb]
2025-06-01 improved grounding trace size and scheme for power supply
    [Power_Supply_V1.0.kicad_pcb]
2025-06-15 Updated Ceramic Capacitor Footprints
    [EQ_Driver_V1.0.kicad_pcb, EQ_Driver_V1.0.kicad_sch, Preamp_Reverb_V1.0.kicad_pcb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]
2025-06-16 Adjusted Resistor Sizes
    [EQ_Driver_V1.0.kicad_pcb, EQ_Driver_V1.0.kicad_sch, EQ_Slider_V1.0.kicad_pcb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]
2025-06-20 Preamp Progress, and Custom Footprint Library
    [EQ_Driver_V1.0.kicad_pcb, EQ_Slider_V1.0.kicad_pcb, Preamp_Reverb_V1.0.kicad_pcb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]
2025-07-03 Updated 12AX7 footprint, resized preamp board
    [Preamp_Reverb_V1.0.kicad_pcb, Preamp_Reverb_V1.0.kicad_sch]
2025-07-05 initial Preamp Traces
    [Preamp_Reverb_V1.0.kicad_pcb]
2025-07-08 Preamp board progress, placed most of parts
    [Preamp_Reverb_V1.0.kicad_pcb]
